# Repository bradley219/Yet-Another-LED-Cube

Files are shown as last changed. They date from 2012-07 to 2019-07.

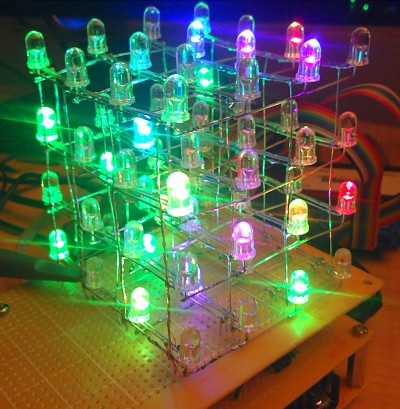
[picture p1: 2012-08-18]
misc/IMG604.jpg

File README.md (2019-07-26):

Yet-Another-LED-Cube
====================

About
-----
An attempt to reinvent..the cube? 

Sorry, this file hasn't had much effort put into it yet :/ A [video](https://fastl.io/eX6) to hold you over for now.

 

Schematic available in PDF and Eagle formats in the \`schematic' directory


Hardware
--------

### LED Matrix Topography

Since I only had enough hardware to create a 4x4x4 cube, I wanted the display to be as robust as
possible. I opted to use the [TLC5940](http://www.ti.com/product/tlc5940) 16-channel constant-current LED driver from Texas
Instruments, which provides 16 independent 12-bit PWM channels, each of which can sink &gt;100mA 
of current. My goal was to be able to use a single 16-channel driver to drive all 192 channels by
using a multiplexing scheme. To acheive this, I grouped the LEDs into individual "pages" of 4 LEDs.
The LEDs within a "page" share a common anode; cathodes are shared among LEDs in corresponding
positions within other pages.

### Drive Theory and Timing



The design of the cube allows for only a single "page" of LEDs to be driven at any given moment. The
16 pages which make up the cube are driven in sequence at about 100Hz (full-cycle period). 

### High-Side Switching
### Low-Side Switching/Current Sink

Software
--------

### Driver
### Driver Interface
### Color Calculations
### Animations

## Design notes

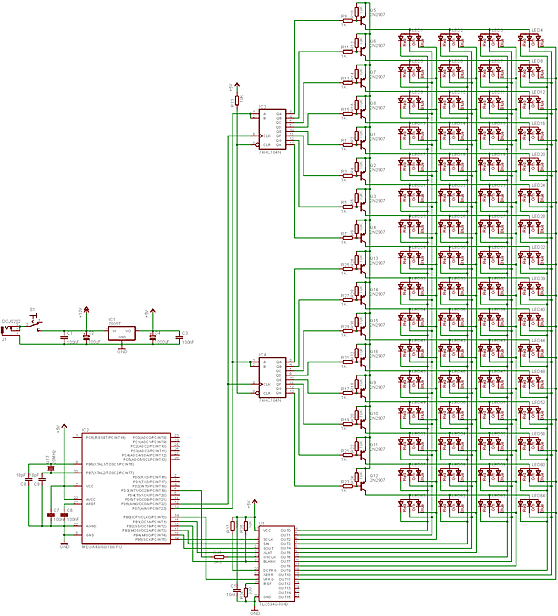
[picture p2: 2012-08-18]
schematic/Yet-Another-LED-Cube.sch.jpg

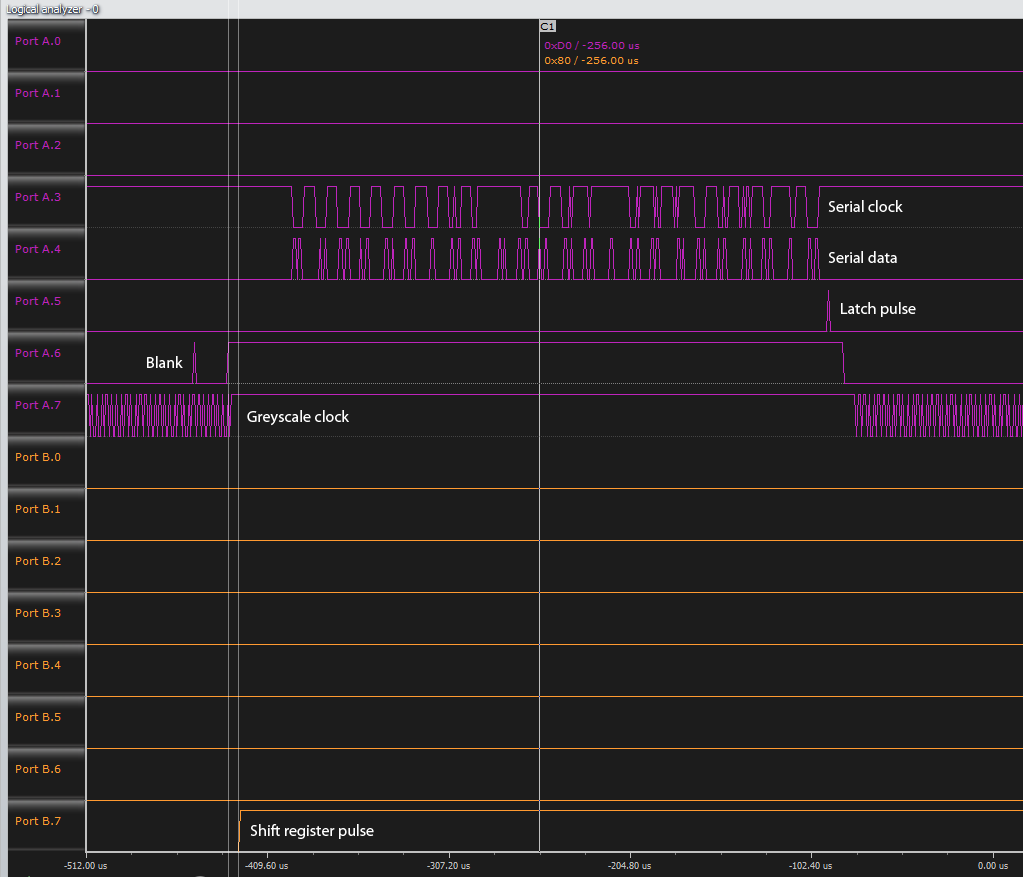
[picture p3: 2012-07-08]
misc/timing.png

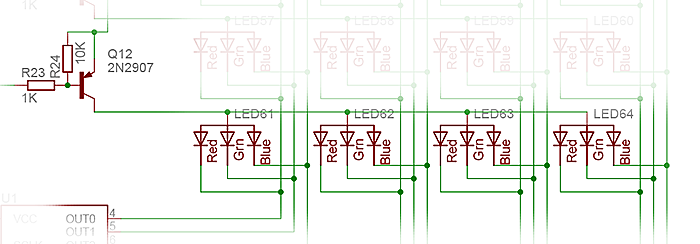
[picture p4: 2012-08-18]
misc/led-page-unit.png

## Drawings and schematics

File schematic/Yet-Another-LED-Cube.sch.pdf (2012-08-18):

2N2907

1K

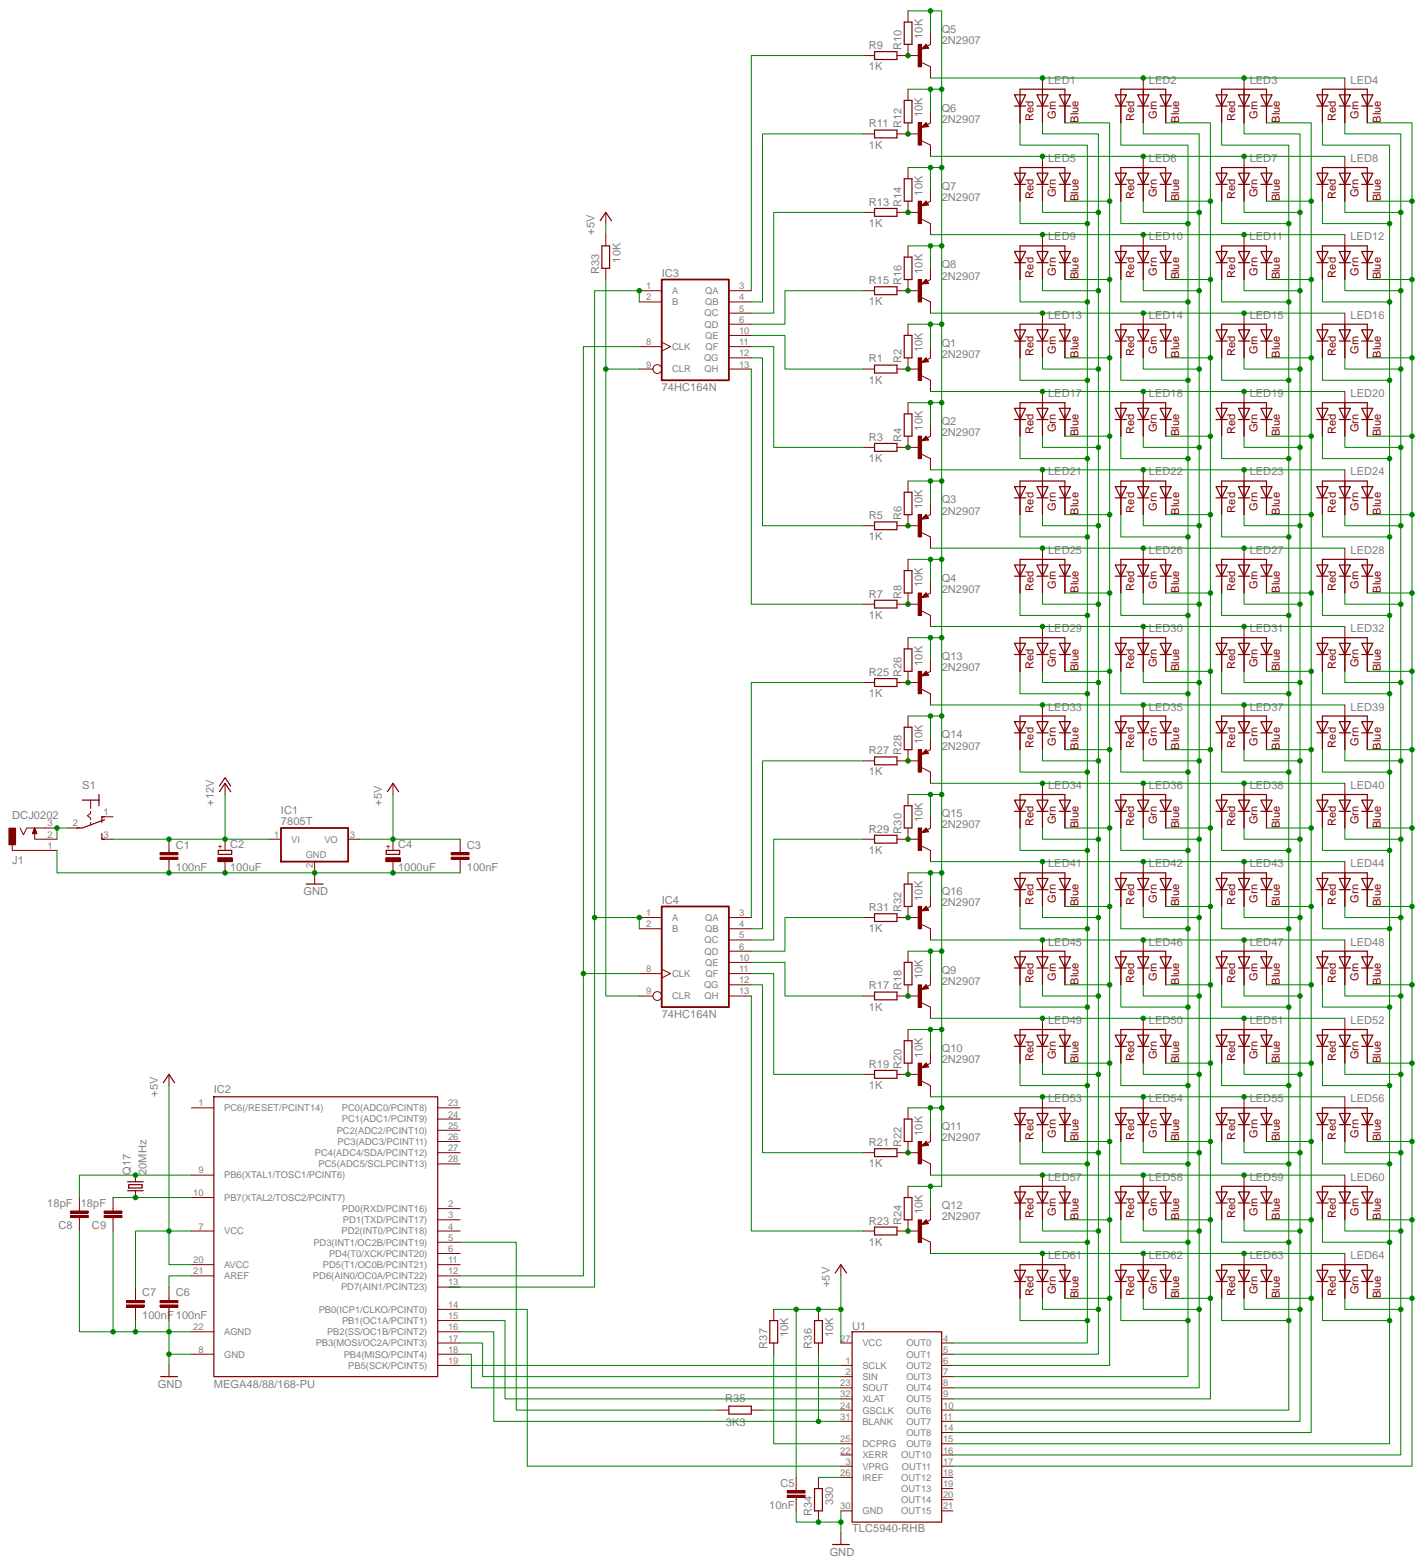
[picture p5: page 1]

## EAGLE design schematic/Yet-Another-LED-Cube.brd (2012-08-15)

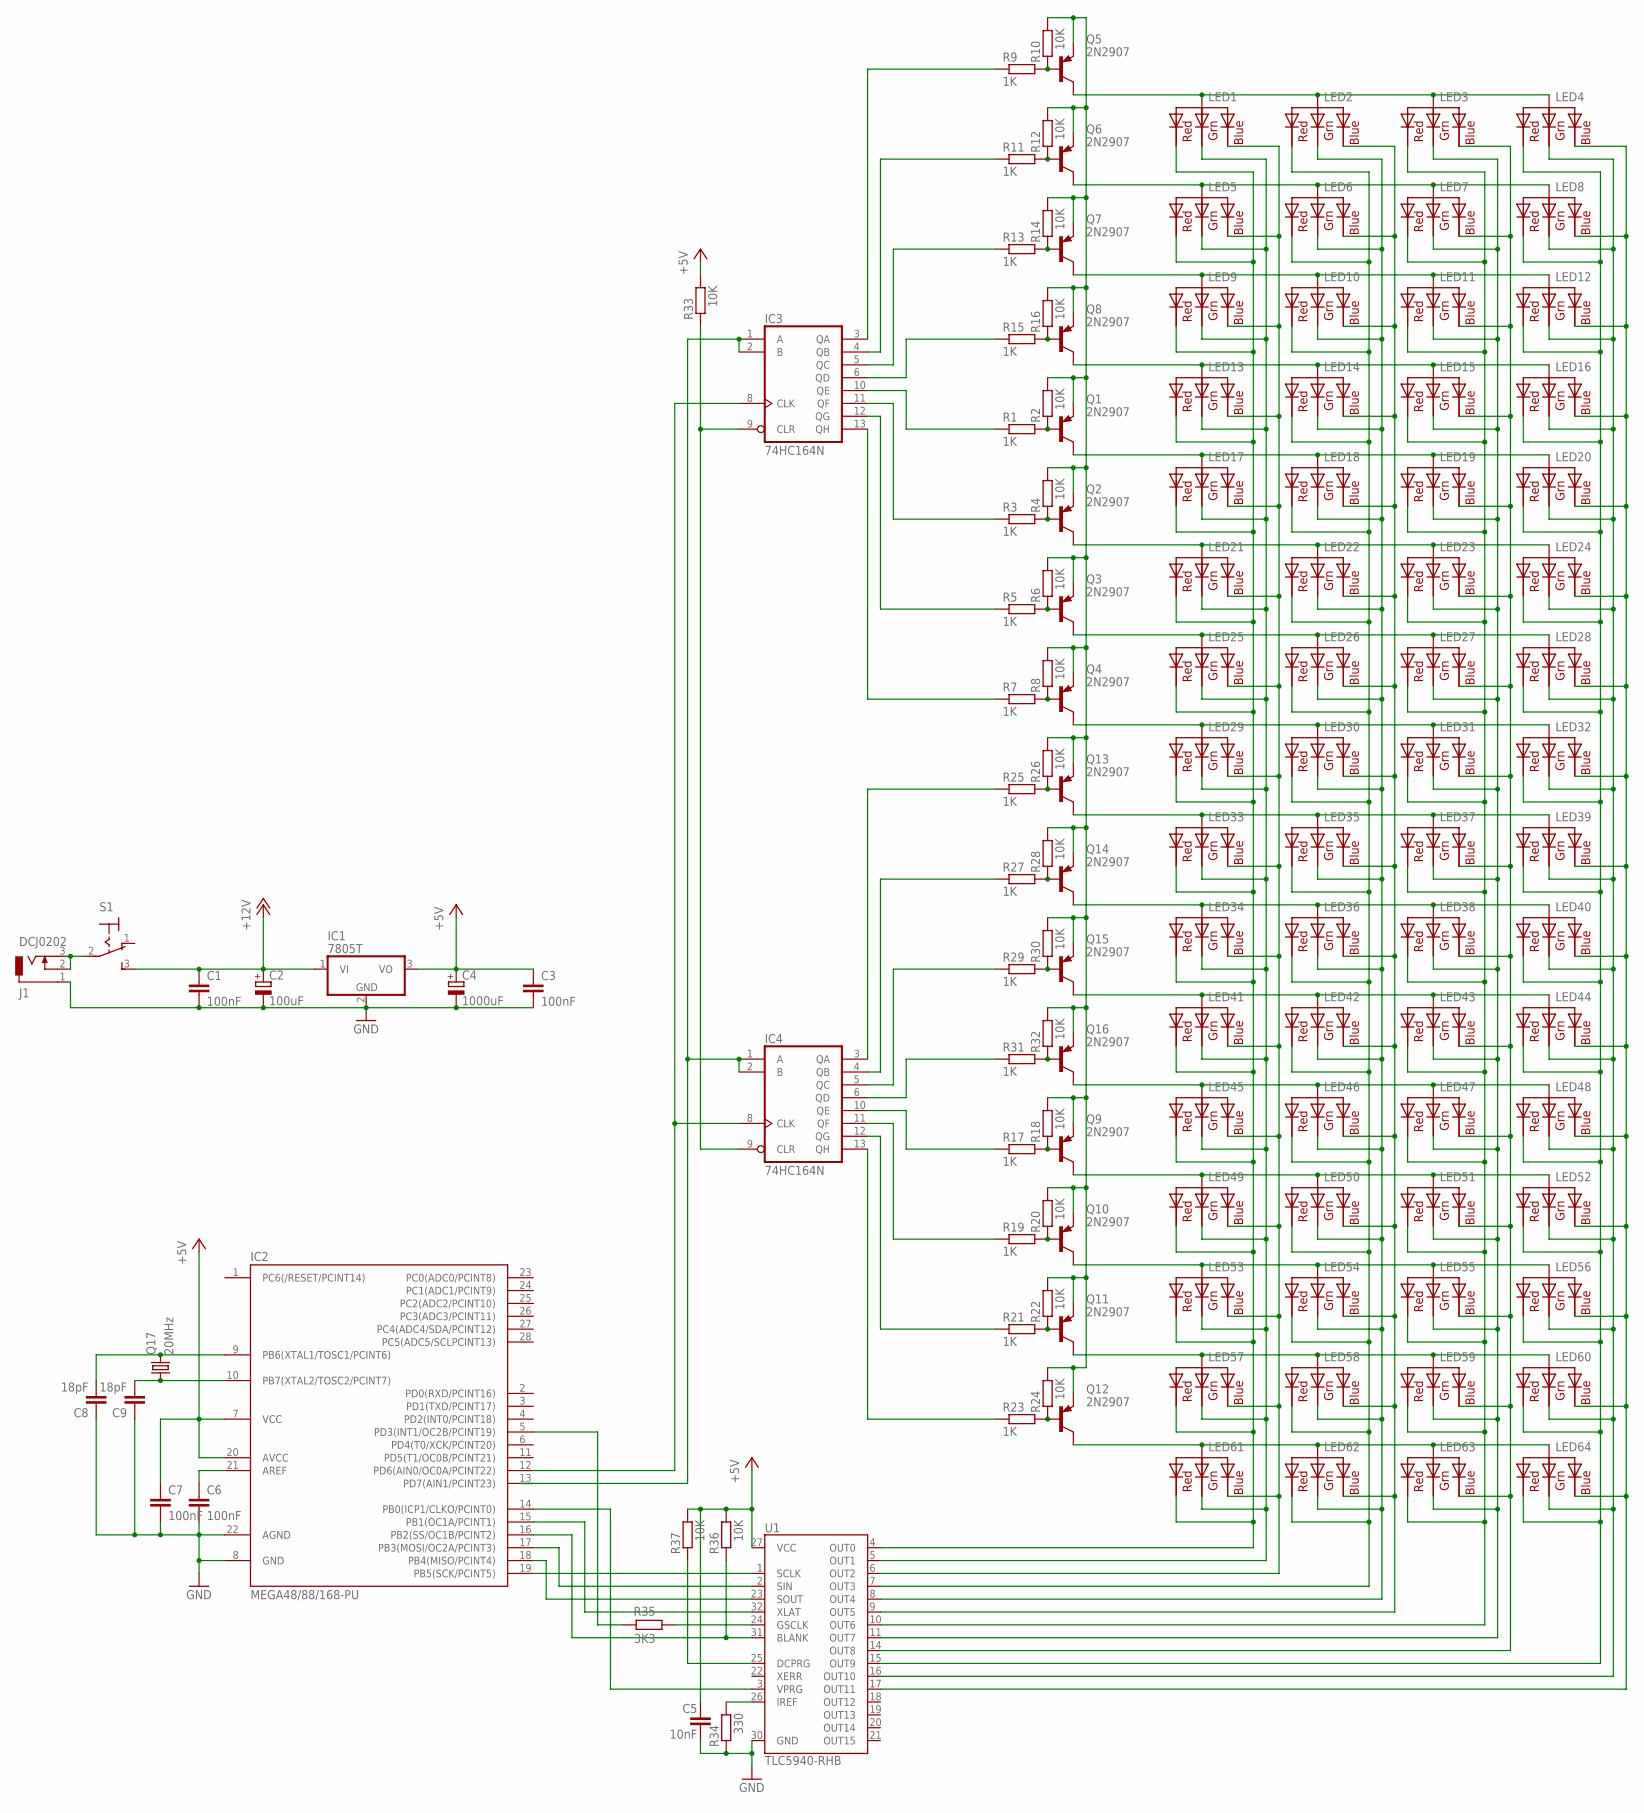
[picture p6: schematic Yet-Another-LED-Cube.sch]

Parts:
C1, C3, C6, C7: 100nF; C025-024X044
C2: 100uF; E2,5-7
C4: 1000uF; E3,5-10
C5: 10nF; C025-024X044
C8, C9: 18pF; C025-024X044
IC1: 7805T; TO220H
IC2: MEGA48/88/168-PU; DIL28-3
IC3, IC4: 74HC164N; DIL14
J1: DCJ0202
LED1, LED2, LED3, LED4, LED5, LED6, LED7, LED8, LED9, LED10, LED11, LED12, LED13, LED14, LED15, LED16, LED17, LED18, LED19, LED20, LED21, LED22, LED23, LED24, LED25, LED26, LED27, LED28, LED29, LED30, LED31, LED32, LED33, LED34, LED35, LED36, LED37, LED38, LED39, LED40, LED41, LED42, LED43, LED44, LED45, LED46, LED47, LED48, LED49, LED50, LED51, LED52, LED53, LED54, LED55, LED56, LED57, LED58, LED59, LED60, LED61, LED62, LED63, LED64: RGBLED_CAA; LED5MMRGB2
Q1, Q2, Q3, Q4, Q5, Q6, Q7, Q8, Q9, Q10, Q11, Q12, Q13, Q14, Q15, Q16: 2N2907; TO18
Q17: 20MHz; HC49/S
R1, R3, R5, R7, R9, R11, R13, R15, R17, R19, R21, R23, R25, R27, R29, R31: 1K; 0204V
R2, R4, R6, R8, R10, R12, R14, R16, R18, R20, R22, R24, R26, R28, R30, R32, R33, R36, R37: 10K; 0204V
R34: 330; 0204V
R35: 3K3; 0204V
S1: 320-916
U1: TLC5940-RHB; QFN-32

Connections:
+5V: C3.1, C4.+, C5.1, C7.1, IC1.3 (VO), IC2.7 (VCC), IC2.20 (AVCC), R33.2, R36.2, R37.2, U1.27 (VCC)
+12V: C1.1, C2.+, IC1.1 (VI), S1.3 (S)
GND: C1.2, C2.-, C3.2, C4.-, C5.2, C6.2, C7.2, C8.1, C9.1, IC1.2 (GND), IC2.8 (GND), IC2.22 (AGND), IC3.7 (GND), IC4.7 (GND), J1.1, R34.1, U1.30 (GND)
unnamed: J1.2, J1.3, S1.2
unnamed: Q1.2 (B), R1.2, R2.1
unnamed: Q2.2 (B), R3.2, R4.1
unnamed: Q3.2 (B), R5.2, R6.1
unnamed: Q4.2 (B), R7.2, R8.1
unnamed: Q5.2 (B), R9.2, R10.1
unnamed: Q6.2 (B), R11.2, R12.1
unnamed: Q7.2 (B), R13.2, R14.1
unnamed: Q8.2 (B), R15.2, R16.1
unnamed: LED1.P$1 (RED), LED5.P$1 (RED), LED9.P$1 (RED), LED13.P$1 (RED), LED17.P$1 (RED), LED21.P$1 (RED), LED25.P$1 (RED), LED29.P$1 (RED), LED33.P$1 (RED), LED34.P$1 (RED), LED41.P$1 (RED), LED45.P$1 (RED), LED49.P$1 (RED), LED53.P$1 (RED), LED57.P$1 (RED), LED61.P$1 (RED), U1.4 (OUT0)
unnamed: IC3.12 (QG), R5.1
unnamed: IC3.11 (QF), R3.1
unnamed: IC3.10 (QE), R1.1
unnamed: IC3.3 (QA), R9.1
unnamed: IC3.4 (QB), R11.1
unnamed: IC3.5 (QC), R13.1
unnamed: IC3.6 (QD), R15.1
unnamed: LED1.P$3 (GREEN), LED5.P$3 (GREEN), LED9.P$3 (GREEN), LED13.P$3 (GREEN), LED17.P$3 (GREEN), LED21.P$3 (GREEN), LED25.P$3 (GREEN), LED29.P$3 (GREEN), LED33.P$3 (GREEN), LED34.P$3 (GREEN), LED41.P$3 (GREEN), LED45.P$3 (GREEN), LED49.P$3 (GREEN), LED53.P$3 (GREEN), LED57.P$3 (GREEN), LED61.P$3 (GREEN), U1.5 (OUT1)
unnamed: Q9.2 (B), R17.2, R18.1
unnamed: Q10.2 (B), R19.2, R20.1
unnamed: Q11.2 (B), R21.2, R22.1
unnamed: Q12.2 (B), R23.2, R24.1
unnamed: Q13.2 (B), R25.2, R26.1
unnamed: Q14.2 (B), R27.2, R28.1
unnamed: Q15.2 (B), R29.2, R30.1
unnamed: Q16.2 (B), R31.2, R32.1
unnamed: IC4.12 (QG), R21.1
unnamed: IC4.11 (QF), R19.1
unnamed: IC4.10 (QE), R17.1
unnamed: IC4.3 (QA), R25.1
unnamed: IC4.4 (QB), R27.1
unnamed: IC4.5 (QC), R29.1
unnamed: IC4.6 (QD), R31.1
unnamed: IC2.19 (PB5(SCK/PCINT5)), U1.1 (SCLK)
unnamed: LED1.P$2 (VCC), LED2.P$2 (VCC), LED3.P$2 (VCC), LED4.P$2 (VCC), Q5.3 (C)
unnamed: IC2.12 (PD6(AIN0/OC0A/PCINT22)), IC3.8 (CLK), IC4.8 (CLK)
unnamed: IC3.1 (A), IC3.2 (B), IC4.1 (A), IC4.2 (B)
unnamed: LED1.P$4 (BLUE), LED5.P$4 (BLUE), LED9.P$4 (BLUE), LED13.P$4 (BLUE), LED17.P$4 (BLUE), LED21.P$4 (BLUE), LED25.P$4 (BLUE), LED29.P$4 (BLUE), LED33.P$4 (BLUE), LED34.P$4 (BLUE), LED41.P$4 (BLUE), LED45.P$4 (BLUE), LED49.P$4 (BLUE), LED53.P$4 (BLUE), LED57.P$4 (BLUE), LED61.P$4 (BLUE), U1.6 (OUT2)
unnamed: IC2.17 (PB3(MOSI/OC2A/PCINT3)), U1.2 (SIN)
unnamed: IC3.9 (CLR), IC4.9 (CLR), R33.1
unnamed: LED5.P$2 (VCC), LED6.P$2 (VCC), LED7.P$2 (VCC), LED8.P$2 (VCC), Q6.3 (C)
unnamed: LED2.P$1 (RED), LED6.P$1 (RED), LED10.P$1 (RED), LED14.P$1 (RED), LED18.P$1 (RED), LED22.P$1 (RED), LED26.P$1 (RED), LED30.P$1 (RED), LED35.P$1 (RED), LED36.P$1 (RED), LED42.P$1 (RED), LED46.P$1 (RED), LED50.P$1 (RED), LED54.P$1 (RED), LED58.P$1 (RED), LED62.P$1 (RED), U1.7 (OUT3)
unnamed: LED2.P$3 (GREEN), LED6.P$3 (GREEN), LED10.P$3 (GREEN), LED14.P$3 (GREEN), LED18.P$3 (GREEN), LED22.P$3 (GREEN), LED26.P$3 (GREEN), LED30.P$3 (GREEN), LED35.P$3 (GREEN), LED36.P$3 (GREEN), LED42.P$3 (GREEN), LED46.P$3 (GREEN), LED50.P$3 (GREEN), LED54.P$3 (GREEN), LED58.P$3 (GREEN), LED62.P$3 (GREEN), U1.8 (OUT4)
unnamed: LED2.P$4 (BLUE), LED6.P$4 (BLUE), LED10.P$4 (BLUE), LED14.P$4 (BLUE), LED18.P$4 (BLUE), LED22.P$4 (BLUE), LED26.P$4 (BLUE), LED30.P$4 (BLUE), LED35.P$4 (BLUE), LED36.P$4 (BLUE), LED42.P$4 (BLUE), LED46.P$4 (BLUE), LED50.P$4 (BLUE), LED54.P$4 (BLUE), LED58.P$4 (BLUE), LED62.P$4 (BLUE), U1.9 (OUT5)
unnamed: IC3.13 (QH), R7.1
unnamed: LED3.P$1 (RED), LED7.P$1 (RED), LED11.P$1 (RED), LED15.P$1 (RED), LED19.P$1 (RED), LED23.P$1 (RED), LED27.P$1 (RED), LED31.P$1 (RED), LED37.P$1 (RED), LED38.P$1 (RED), LED43.P$1 (RED), LED47.P$1 (RED), LED51.P$1 (RED), LED55.P$1 (RED), LED59.P$1 (RED), LED63.P$1 (RED), U1.10 (OUT6)
unnamed: LED3.P$3 (GREEN), LED7.P$3 (GREEN), LED11.P$3 (GREEN), LED15.P$3 (GREEN), LED19.P$3 (GREEN), LED23.P$3 (GREEN), LED27.P$3 (GREEN), LED31.P$3 (GREEN), LED37.P$3 (GREEN), LED38.P$3 (GREEN), LED43.P$3 (GREEN), LED47.P$3 (GREEN), LED51.P$3 (GREEN), LED55.P$3 (GREEN), LED59.P$3 (GREEN), LED63.P$3 (GREEN), U1.11 (OUT7)
unnamed: LED3.P$4 (BLUE), LED7.P$4 (BLUE), LED11.P$4 (BLUE), LED15.P$4 (BLUE), LED19.P$4 (BLUE), LED23.P$4 (BLUE), LED27.P$4 (BLUE), LED31.P$4 (BLUE), LED37.P$4 (BLUE), LED38.P$4 (BLUE), LED43.P$4 (BLUE), LED47.P$4 (BLUE), LED51.P$4 (BLUE), LED55.P$4 (BLUE), LED59.P$4 (BLUE), LED63.P$4 (BLUE), U1.14 (OUT8)
unnamed: IC2.18 (PB4(MISO/PCINT4)), U1.23 (SOUT)
unnamed: LED4.P$1 (RED), LED8.P$1 (RED), LED12.P$1 (RED), LED16.P$1 (RED), LED20.P$1 (RED), LED24.P$1 (RED), LED28.P$1 (RED), LED32.P$1 (RED), LED39.P$1 (RED), LED40.P$1 (RED), LED44.P$1 (RED), LED48.P$1 (RED), LED52.P$1 (RED), LED56.P$1 (RED), LED60.P$1 (RED), LED64.P$1 (RED), U1.15 (OUT9)
unnamed: LED4.P$3 (GREEN), LED8.P$3 (GREEN), LED12.P$3 (GREEN), LED16.P$3 (GREEN), LED20.P$3 (GREEN), LED24.P$3 (GREEN), LED28.P$3 (GREEN), LED32.P$3 (GREEN), LED39.P$3 (GREEN), LED40.P$3 (GREEN), LED44.P$3 (GREEN), LED48.P$3 (GREEN), LED52.P$3 (GREEN), LED56.P$3 (GREEN), LED60.P$3 (GREEN), LED64.P$3 (GREEN), U1.16 (OUT10)
unnamed: LED4.P$4 (BLUE), LED8.P$4 (BLUE), LED12.P$4 (BLUE), LED16.P$4 (BLUE), LED20.P$4 (BLUE), LED24.P$4 (BLUE), LED28.P$4 (BLUE), LED32.P$4 (BLUE), LED39.P$4 (BLUE), LED40.P$4 (BLUE), LED44.P$4 (BLUE), LED48.P$4 (BLUE), LED52.P$4 (BLUE), LED56.P$4 (BLUE), LED60.P$4 (BLUE), LED64.P$4 (BLUE), U1.17 (OUT11)
unnamed: Q1.1 (E), Q2.1 (E), Q3.1 (E), Q4.1 (E), Q5.1 (E), Q6.1 (E), Q7.1 (E), Q8.1 (E), Q9.1 (E), Q10.1 (E), Q11.1 (E), Q12.1 (E), Q13.1 (E), Q14.1 (E), Q15.1 (E), Q16.1 (E), R2.2, R4.2, R6.2, R8.2, R10.2, R12.2, R14.2, R16.2, R18.2, R20.2, R22.2, R24.2, R26.2, R28.2, R30.2, R32.2
unnamed: IC2.15 (PB1(OC1A/PCINT1)), U1.32 (XLAT)
unnamed: IC2.5 (PD3(INT1/OC2B/PCINT19)), R35.2
unnamed: IC2.16 (PB2(SS/OC1B/PCINT2)), R36.1, U1.31 (BLANK)
unnamed: IC2.14 (PB0(ICP1/CLKO/PCINT0)), U1.3 (VPRG)
unnamed: R34.2, U1.26 (IREF)
unnamed: R35.1, U1.24 (GSCLK)
unnamed: R37.1, U1.25 (DCPRG)
unnamed: LED33.P$2 (VCC), LED35.P$2 (VCC), LED37.P$2 (VCC), LED39.P$2 (VCC), Q13.3 (C)
unnamed: LED34.P$2 (VCC), LED36.P$2 (VCC), LED38.P$2 (VCC), LED40.P$2 (VCC), Q14.3 (C)
unnamed: LED61.P$2 (VCC), LED62.P$2 (VCC), LED63.P$2 (VCC), LED64.P$2 (VCC), Q12.3 (C)
unnamed: LED57.P$2 (VCC), LED58.P$2 (VCC), LED59.P$2 (VCC), LED60.P$2 (VCC), Q11.3 (C)
unnamed: LED53.P$2 (VCC), LED54.P$2 (VCC), LED55.P$2 (VCC), LED56.P$2 (VCC), Q10.3 (C)
unnamed: LED49.P$2 (VCC), LED50.P$2 (VCC), LED51.P$2 (VCC), LED52.P$2 (VCC), Q9.3 (C)
unnamed: LED45.P$2 (VCC), LED46.P$2 (VCC), LED47.P$2 (VCC), LED48.P$2 (VCC), Q16.3 (C)
unnamed: LED41.P$2 (VCC), LED42.P$2 (VCC), LED43.P$2 (VCC), LED44.P$2 (VCC), Q15.3 (C)
unnamed: IC4.13 (QH), R23.1
unnamed: C6.1, IC2.21 (AREF)
unnamed: C8.2, IC2.9 (PB6(XTAL1/TOSC1/PCINT6)), Q17.2
unnamed: C9.2, IC2.10 (PB7(XTAL2/TOSC2/PCINT7)), Q17.1
unnamed: LED29.P$2 (VCC), LED30.P$2 (VCC), LED31.P$2 (VCC), LED32.P$2 (VCC), Q4.3 (C)
unnamed: LED25.P$2 (VCC), LED26.P$2 (VCC), LED27.P$2 (VCC), LED28.P$2 (VCC), Q3.3 (C)
unnamed: LED21.P$2 (VCC), LED22.P$2 (VCC), LED23.P$2 (VCC), LED24.P$2 (VCC), Q2.3 (C)
unnamed: LED17.P$2 (VCC), LED18.P$2 (VCC), LED19.P$2 (VCC), LED20.P$2 (VCC), Q1.3 (C)
unnamed: LED13.P$2 (VCC), LED14.P$2 (VCC), LED15.P$2 (VCC), LED16.P$2 (VCC), Q8.3 (C)
unnamed: LED9.P$2 (VCC), LED10.P$2 (VCC), LED11.P$2 (VCC), LED12.P$2 (VCC), Q7.3 (C)
VCC: IC3.14 (VCC), IC4.14 (VCC)

Board: 2 copper layers, 134 parts (0 on the bottom side), 82 nets, no tracks yet.

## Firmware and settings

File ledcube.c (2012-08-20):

#ifndef _LEDCUBE_SOURCE_
#define _LEDCUBE_SOURCE_
#include "ledcube.h"
#include <avr/interrupt.h>
#include <avr/eeprom.h>
#include <util/delay.h>

hsb_t main_color = { .h = 0, .s = 1, .b = 0.5 };
uint8_t is_beat = 0;

int main(void)
{
	//audio_init();

	eeprom_srand();

	tlc_set_all_gs(0);
	tlc_gs_data_latch();
	
	led_driver_init();

	//cubes_init();
	//fader_init();
	
	uint16_t g = 0;//PWM_MAX_VAL * 7 / 8;
	char inc = 1;
	snake_init();
	//tlc_set_all_gs(4095);
	//tlc_gs_data_latch();
	//while(1) 
	//{
	//}
	while(1) 
	{
		//rando();
		//solid_fader_task();
		//fader_task();
		//led_test5();
		//cubes_task();
		//audio_task();
		snake_task();
		//panels_task();
	}
	return 0;
}

static unsigned long EEMEM analog_seed = 0;
void eeprom_srand(void)
{
	volatile unsigned long seed;
	eeprom_read_block( &seed, &analog_seed, sizeof(analog_seed) );
	srand(seed);
	seed++;
	eeprom_write_block( &seed, &analog_seed, sizeof(analog_seed) );
	return;
}
#endif

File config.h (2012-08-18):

#ifndef _CONFIG_H_
#define _CONFIG_H_

// Audio
#define FFT_N	64		/* Number of samples (64,128,256,512). Don't forget to clean! */
#define AUDIO_BUFFER_SIZE FFT_N

// Cubes
#define CUBE_SIZE 2
#define CUBE_HEIGHT CUBE_SIZE
#define CUBE_WIDTH CUBE_SIZE
#define CUBE_DEPTH CUBE_SIZE

#define DISALLOW_UNDO_OF_PREVIOUS_SLIDE
#define CUBE_STEP_ANIMATION_DELAY_MS 30
#define CUBE_SWAP_DELAY_MS 200

// Random bugs
#define NUM_BUGS 20

/**
 * TLC
 */
#define NUM_ROWS 16
#define NUM_TLC_CHANNELS (NUM_TLC_CHIPS * 16)
#define TLC_DC_BYTES (NUM_TLC_CHANNELS*6/8)
#define TLC_GS_ROW_BYTES (NUM_TLC_CHANNELS*12/8)
#define TLC_GS_BYTES (TLC_GS_ROW_BYTES*NUM_ROWS)

//#define TLC_PWM_PERIOD (4096 * 1)

#define PWM_MAX_VAL (4095)
#define PWM_MAX_BLUE  PWM_MAX_VAL
#define PWM_MAX_GREEN PWM_MAX_VAL
#define PWM_MAX_RED   PWM_MAX_VAL

#define DOT_CORRECTION_BLUE  63
#define DOT_CORRECTION_GREEN 63
#define DOT_CORRECTION_RED 	 48

#define LED_SIZE 4
#define LED_WIDTH LED_SIZE
#define LED_HEIGHT LED_SIZE
#define LED_DEPTH LED_SIZE

#define TIMER2_GS_TRIGGER 1
#define TIMER2_TOPVAL 3
#define TLC_PWM_PERIOD (PWM_MAX_VAL*2)
#define TLC_CYCLE_COUNTS_PER_MULTIPLEX 2

#define LED_MAX_DIMENSION LED_WIDTH

#if LED_DEPTH > LED_MAX_DIMENSION 
#undef LED_MAX_DIMENSION
#define LED_MAX_DIMENSION LED_DEPTH
#endif

#if LED_HEIGHT > LED_MAX_DIMENSION 
#undef LED_MAX_DIMENSION
#define LED_MAX_DIMENSION LED_HEIGHT
#endif

/**
 * DEBUGGING
 */
#define DEBUGGING 1

#define NUM_TLC_CHIPS 1

/**
 * Pins
 */
#define TLC_VPRG_PORT_LETTER B
#define TLC_VPRG_PORT_NUMBER 0

#define TLC_SIN_PORT_LETTER B
#define TLC_SIN_PORT_NUMBER 3

#define TLC_SCLK_PORT_LETTER B
#define TLC_SCLK_PORT_NUMBER 5

#define TLC_XLAT_PORT_LETTER B
#define TLC_XLAT_PORT_NUMBER 1

#define TLC_BLANK_PORT_LETTER B
#define TLC_BLANK_PORT_NUMBER 2

#define TLC_GSCLK_PORT_LETTER D
#define TLC_GSCLK_PORT_NUMBER 3

#define TLC_XERR_PORT_LETTER B // FIXME: PORTB4 should be connected to TLC's SOUT; XERR is a flag signal
#define TLC_XERR_PORT_NUMBER 4

#define SHIFT_REG_CP_PORT_LETTER D
#define SHIFT_REG_CP_PORT_NUMBER 6
#define SHIFT_REG_SIN_PORT_LETTER D
#define SHIFT_REG_SIN_PORT_NUMBER 7



/* Timer prescales */
#define TIMER0_PRESCALE 8
#define TIMER1_PRESCALE 1
#define TIMER2_PRESCALE TIMER1_PRESCALE
#define SPI_PRESCALE 2

/* Prescales */
#if SPI_PRESCALE == 4
#define SPI2X_BIT 0
#define SPI_PS_BITS 0
#elif SPI_PRESCALE == 16
#define SPI2X_BIT 0
#define SPI_PS_BITS (_BV(SPR0))
#elif SPI_PRESCALE == 64
#define SPI2X_BIT 0
#define SPI_PS_BITS (_BV(SPR1))
#elif SPI_PRESCALE == 128
#define SPI2X_BIT 0
#define SPI_PS_BITS (_BV(SPR1)|_BV(WPR0))
#elif SPI_PRESCALE == 2
#define SPI2X_BIT (_BV(SPI2X))
#define SPI_PS_BITS 0
#elif SPI_PRESCALE == 8
#define SPI2X_BIT (_BV(SPI2X))
#define SPI_PS_BITS (_BV(SPR0))
#elif SPI_PRESCALE == 32
#define SPI2X_BIT (_BV(SPI2X))
#define SPI_PS_BITS (_BV(SPR1))
#elif SPI_PRESCALE == 64
#define SPI2X_BIT (_BV(SPI2X))
#define SPI_PS_BITS (_BV(SPR1)|_BV(WPR0))
#endif


#if TIMER0_PRESCALE == 1024
#define TIMER0_PS_BITS ( _BV(CS02) | _BV(CS00) )
#elif TIMER0_PRESCALE == 256
#define TIMER0_PS_BITS ( _BV(CS02) )
#elif TIMER0_PRESCALE == 64
#define TIMER0_PS_BITS ( _BV(CS01) | _BV(CS00) )
#elif TIMER0_PRESCALE == 8
#define TIMER0_PS_BITS ( _BV(CS01) )
#elif TIMER0_PRESCALE == 1
#define TIMER0_PS_BITS ( _BV(CS00) )
#elif TIMER0_PRESCALE == 0
#define TIMER0_PS_BITS ( 0 )
#else 
#error "TIMER0_PRESCALE is invalid!"
#endif

#if TIMER1_PRESCALE == 1024
#define TIMER1_PS_BITS ( _BV(CS12) | _BV(CS10) )
#elif TIMER1_PRESCALE == 256
#define TIMER1_PS_BITS ( _BV(CS12) )
#elif TIMER1_PRESCALE == 64
#define TIMER1_PS_BITS ( _BV(CS11) | _BV(CS10) )
#elif TIMER1_PRESCALE == 8
#define TIMER1_PS_BITS ( _BV(CS11) )
#elif TIMER1_PRESCALE == 1
#define TIMER1_PS_BITS ( _BV(CS10) )
#elif TIMER1_PRESCALE == 0
#define TIMER1_PS_BITS ( 0 )
#else 
#error "TIMER1_PRESCALE is invalid!"
#endif

#if TIMER2_PRESCALE == 1024
#define TIMER2_PS_BITS ( _BV(CS22) | _BV(CS21) | _BV(CS20) )
#elif TIMER2_PRESCALE == 256
#define TIMER2_PS_BITS ( _BV(CS21) | _BV(CS22) )
#elif TIMER2_PRESCALE == 128
#define TIMER2_PS_BITS ( _BV(CS22) | _BV(CS20) )
#elif TIMER2_PRESCALE == 64
#define TIMER2_PS_BITS ( _BV(CS22) )
#elif TIMER2_PRESCALE == 32
#define TIMER2_PS_BITS ( _BV(CS21) | _BV(CS20) )
#elif TIMER2_PRESCALE == 8
#define TIMER2_PS_BITS ( _BV(CS21) )
#elif TIMER2_PRESCALE == 1
#define TIMER2_PS_BITS ( _BV(CS20) )
#elif TIMER2_PRESCALE == 1
#define TIMER2_PS_BITS ( 0 )
#else
#error "TIMER2_PRESCALE is invalid!"
#endif


#endif

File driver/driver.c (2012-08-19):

#ifndef _DRIVER_SOURCE_
#define _DRIVER_SOURCE_

#include "ports.h"
#include <string.h>
#include <avr/io.h>
#include <avr/interrupt.h>
#include <util/delay.h>
#include "types.h"
#include "config.h"
#include "driver.h"
#include "asmdriver.h"

#define TLC_DC_INPUT_MODE() TLC_VPRG_PORT |= _BV(TLC_VPRG)
#define TLC_LATCH() TLC_XLAT_PORT |= _BV(TLC_XLAT); TLC_XLAT_PORT &= ~_BV(TLC_XLAT)

volatile uint8_t auto_gs_enabled = 0;
volatile uint8_t tlc_cycle_counts = TLC_CYCLE_COUNTS_PER_MULTIPLEX;
volatile uint16_t current_row = 0;
static uint8_t tlc_dot_correction_data[TLC_DC_BYTES];

uint8_t tlc_gs_live_data[TLC_GS_BYTES];
//#define tlc_gs_data tlc_gs_live_data
static uint8_t tlc_gs_data[TLC_GS_BYTES];

volatile uint8_t spi_bytes_remaining = TLC_GS_ROW_BYTES;
volatile uint8_t *spi_gsd = tlc_gs_live_data + sizeof(tlc_gs_live_data) - TLC_GS_ROW_BYTES;

void tlc_timer_init(void)
{
	// GSCLK timer -- high frequency
	TCCR2A = _BV(COM2B1) | _BV(WGM21) | _BV(WGM20);
	OCR2B = TIMER2_GS_TRIGGER;
	OCR2A = TIMER2_TOPVAL; // TOP value - min value is 3
	TCCR2B = _BV(WGM22) | TIMER2_PS_BITS; // no prescale, start

	// Timer 1 - BLANK / XLAT 
	TCCR1A = _BV(COM1B1);  // non inverting, output on OC1B, BLANK
	OCR1A = 1;             // duty factor on OC1A, XLAT is inside BLANK
	OCR1B = 2;             // duty factor on BLANK (larger than OCR1A (XLAT))
	ICR1 = TLC_PWM_PERIOD + 76 / 2;  // 76 is the minimum number of clock cycles the ISR takes to complete
	TCCR1B = _BV(WGM13) | TIMER1_PS_BITS;   // Phase/freq correct PWM, ICR1 top, no prescale, start
	TIMSK1 = _BV(TOIE1);
	sei();
	return;
}

/**
 * SPI
 */
void tlc_spi_init(void)
{
	// DDRs
	TLC_BLANK_DDR |= _BV(TLC_BLANK); // SS
	TLC_BLANK_PORT |= _BV(TLC_BLANK);

	TLC_SIN_DDR |= _BV(TLC_SIN); // MOSI
	
	TLC_SCLK_DDR |= _BV(TLC_SCLK); // SCK
	TLC_SCLK_PORT &= ~_BV(TLC_SCLK);

	SPCR = _BV(SPE) | _BV(MSTR);// | SPI_PS_BITS;
	SPSR |= _BV(SPI2X);
	return;
}

void tlc_sclk_strobe(void) // special case
{
	uint8_t spcr = SPCR;
	TLC_SCLK_DDR |= _BV(TLC_SCLK); // SCK

	SPCR &= ~_BV(SPE); // Disable SPI

	TLC_SCLK_PORT |= _BV(TLC_SCLK); // SCLK high
	TLC_SCLK_PORT &= ~_BV(TLC_SCLK); // SCLK low

	SPCR = spcr; // restore SPI state
	return;
}

// TLC data setting methods
void tlc_set_dc( uint8_t channel, uint8_t dc )
{
	uint8_t triplet_idx = channel/4;
	channel -= ( 4 * triplet_idx );
	triplet_idx *= 3;
	
	uint8_t *byte0 = tlc_dot_correction_data + triplet_idx;
	uint8_t *byte1 = byte0+1;
	uint8_t *byte2 = byte1+1;

	switch(channel)
	{
		case 0:
			*byte0 = (*byte0 & 0xc0) | ( dc & 0x3f );
			break;
		case 1:
			*byte0 = (*byte0 & 0x3f) | (( dc & 0x03 ) << 6 );
			*byte1 = (*byte1 & 0xf0) | (dc >> 2);
			break;
		case 2:
			*byte1 = (*byte1 & 0x0f) | ((dc & 0x0f) << 4 );
			*byte2 = (*byte2 & 0xfc) | (dc >> 4);
			break;
		case 3:
			*byte2 = (*byte2 & 0x03) | (dc << 2);
			break;
	}

	return;
}
void tlc_set_all_dc( uint8_t dc )
{
	for( uint16_t i = 0; i < NUM_TLC_CHANNELS; i++ )
	{
		tlc_set_dc( i, dc );
	}
	return;
}
void tlc_shift8( uint8_t byte )
{
	SPDR = byte;
	while( !(SPSR & _BV(SPIF)) );
	return;
}
void tlc_update_dc(void)
{
	TLC_DC_INPUT_MODE();

	uint16_t bytes = TLC_DC_BYTES;
	uint8_t *dcd = tlc_dot_correction_data + TLC_DC_BYTES - 1;
	while(bytes--)
	{
		tlc_shift8(*dcd--);
	}
	TLC_LATCH(); // latch data

	// Send GS data, then strobe SCK
	uint8_t c = TLC_GS_ROW_BYTES;
	while(c--)
	{
		SPDR = 0;
		while( !(SPSR & _BV(SPIF)) );
	}
	tlc_sclk_strobe();

	return;
}

void tlc_set_gs( uint8_t channel, uint8_t row, uint16_t gs )
{
	uint8_t triplet_idx = channel/2;
	channel -= ( 2 * triplet_idx );
	triplet_idx *= 3;
	
	uint8_t *byte0 = tlc_gs_data + (row*TLC_GS_ROW_BYTES) + triplet_idx;
	uint8_t *byte1 = byte0+1;
	uint8_t *byte2 = byte1+1;

	switch(channel)
	{
		case 0:
			*byte0 = gs & 0xff;
			*byte1 = (*byte1 & 0xf0) | (gs >> 8);
			break;
		case 1:
			*byte1 = (*byte1 & 0x0f) | ((gs & 0x0f) << 4);
			*byte2 = gs >> 4;
			break;
	}

	return;
}
void tlc_get_gs( uint8_t channel, uint8_t row, uint16_t *gs )
{
	uint8_t triplet_idx = channel/2;
	channel -= ( 2 * triplet_idx );
	triplet_idx *= 3;
	
	uint8_t *byte0 = tlc_gs_data + (row*TLC_GS_ROW_BYTES) + triplet_idx;
	uint8_t *byte1 = byte0+1;
	uint8_t *byte2 = byte1+1;

	switch(channel)
	{
		case 0:
			//*byte0 = gs & 0xff;
			*gs = *byte0;
			//*byte1 = (*byte1 & 0xf0) | (gs >> 8);
			*gs |= (*byte1 & 0x0f) << 8;
			break;
		case 1:
			*gs = *byte2 << 4;
			*gs |= (*byte1 & 0xf0) >> 4;

			//*byte1 = (*byte1 & 0x0f) | ((gs & 0x0f) << 4);
			//*byte2 = gs >> 4;
			break;
	}
	return;
}
void tlc_set_all_gs( uint16_t gs )
{
	for( uint8_t row = 0; row < NUM_ROWS; row++ )
	{
		for( uint16_t i = 0; i < NUM_TLC_CHANNELS; i++ )
		{
			tlc_set_gs( i, row, gs );
		}
	}
	return;
}
void tlc_gs_data_latch(void)
{
	memcpy( tlc_gs_live_data, tlc_gs_data, sizeof(tlc_gs_data) );
	return;
}
void tlc_set_all_dc_rgb( rgb_t *dc )
{
	for( int i = 0; i < 4; i++ )
	{
		tlc_set_dc( i * 3 + 0, dc->r );
		tlc_set_dc( i * 3 + 1, dc->g );
		tlc_set_dc( i * 3 + 2, dc->b );
	}
}


void tlc_init(void)
{
	// Set in/out data-directions
	TLC_VPRG_PORT &= ~_BV(TLC_VPRG);
	TLC_VPRG_DDR |= _BV(TLC_VPRG); 

	TLC_BLANK_PORT |= _BV(TLC_BLANK);
	
	TLC_BLANK_DDR |= _BV(TLC_BLANK);
	TLC_GSCLK_DDR |= _BV(TLC_GSCLK);
	TLC_XLAT_DDR |= _BV(TLC_XLAT);

	rgb_t dc_rgb = { 
		.r = DOT_CORRECTION_RED, 
		.g = DOT_CORRECTION_GREEN, 
		.b = DOT_CORRECTION_BLUE
	};
	tlc_set_all_dc_rgb( &dc_rgb );
	
	tlc_spi_init();
	tlc_update_dc();

	auto_gs_enabled = 1;
	//tlc_gs_start_spi_chain();
	
	TLC_VPRG_PORT &= ~_BV(TLC_VPRG);
	SPSR |= _BV(SPIF);
	SPCR |= _BV(SPIE);

	tlc_timer_init();
	
	tlc_set_all_gs(0);
	tlc_gs_data_latch();
	
	return;
}

/**
 * Shift register 
 */
void shift_register_init(void) 
{
	SHIFT_REG_CP_DDR  |= _BV(SHIFT_REG_CP);
	SHIFT_REG_SIN_DDR |= _BV(SHIFT_REG_SIN);

	SHIFT_REG_CP_PORT &= ~_BV(SHIFT_REG_CP);
	SHIFT_REG_SIN_PORT &= ~_BV(SHIFT_REG_SIN);

	return;
}

void set_led_raw( uint8_t x, uint8_t y, uint8_t z, uint16_t red, uint16_t green, uint16_t blue )
{
	uint8_t row = y + z * 4; // FIXME: don't hardcode 

	uint8_t chanstart = x * 3;
	tlc_set_gs( chanstart,   row, red );
	tlc_set_gs( chanstart+1, row, green );
	tlc_set_gs( chanstart+2, row, blue );

	return;
}
void set_led( uint8_t x, uint8_t y, uint8_t z, rgb_t *color )
{
	uint8_t row = y + z * 4; // FIXME: don't hardcode 

	uint8_t chanstart = x * 3;

	uint16_t red = color->r * (double)PWM_MAX_RED;
	uint16_t green = color->g * (double)PWM_MAX_GREEN;
	uint16_t blue = color->b * (double)PWM_MAX_BLUE;

	tlc_set_gs( chanstart,   row, red );
	tlc_set_gs( chanstart+1, row, green );
	tlc_set_gs( chanstart+2, row, blue );

	return;
}
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

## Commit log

2012-07-02 Interrupt-based latching
2012-07-02 adj params to fix choppiness
    [ledcube.c]
2012-07-06 translated some driver functions into assembly
2012-07-07 Refactored the LED driver core
2012-07-08 More asm driver conversions
2012-07-08 Deleted unnecessary XLAT interrupt pulse
2012-07-09 fixed PWM timing err found w/oscilloscope
    [config.h, driver.c, ledcube.c]
2012-07-11 Interrupt-based SPI data latching
2012-07-11 Worked out all ISR kinks with new driver
2012-07-11 Fixed gs data pointer initialization
    [driver.c, ledcube.c]
2012-07-22 Optimized SPI ISR routine in assembly
2012-08-14 added board
    [Yet-Another-LED-Cube.brd, Yet-Another-LED-Cube.sch]
2012-08-14 added a bunch of parts
    [Yet-Another-LED-Cube.brd, Yet-Another-LED-Cube.sch]
2012-08-15 Changed shift register port/pin defs
2012-08-15 Add RGB LED parts; connect IC's
    [Yet-Another-LED-Cube.brd, Yet-Another-LED-Cube.sch]
2012-08-15 Add PDF version of schematic
2012-08-18 add JPEG preview of schematic
2012-08-18 add schematic to readme file
2012-08-18 update schematic
    [Yet-Another-LED-Cube.sch]
2012-08-18 add LED page unit diagram
2012-08-18 shrink led page image
